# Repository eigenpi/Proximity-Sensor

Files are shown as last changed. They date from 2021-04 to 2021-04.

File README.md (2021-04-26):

cristinel.ababei, 2021 

Project: Proximity Sensor Design

--Description: 
This is a plug-and-play printed circuit board (PCB) proximity sensor design. It detects metal targets approaching perpendicularly as well as their moving direction. It uses an inductance to digital converter circuit. Machine learning models are used to differentiate between different types of metals (in V2 only). All HW and SW source files are included. HW includes PCB layout files in KiCad and SW includes firmware for the microcontroller (Atmega328p). 

--Short video domonstration: 
https://youtu.be/9pmw1QUPN_U

--More details in conference paper:
[1] Cristinel Ababei and James E. Richie, Sensor Design for Inductive Proximity and Moving Direction Sensing of Metal Targets, IEEE Int. Conf. on Modern Circuits and Systems Technologies (MOCAST), Thessaloniki, Greece, July 2021.

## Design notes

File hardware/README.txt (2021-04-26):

cristinel.ababei, 2020

These are KiCad complete projects for:

--Base board
ProximityMother_V1/

--Single LC tank, 7 turns
ProximityTankOne_Square7Turns/

--Dual LC tank, 14 turns each
ProximityTankTwo_V1/

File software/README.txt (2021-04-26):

cristinel.ababei, 2020

Code here is used in the first generation of a proximity sensor design formed by:

1--base board = Atmega328p + LDC inductance to digital converter
   this is called also Proximity Board in the comments of the code here;
2--two separate sensor boards, one LC tanks, two LC tanks
   each of the sensor boards is a plug-and-play board; the one with one LC tank
   can be used for detecting metal targets approaching perpendicularly to
   the sensor board plane' the sensor board with two LC tanks can be used for
   detecting metal targets moving laterally;

The LDC inductance to digital converter has two operation modes, which
you can select in the code below by selecting one of the following when
the "my_ldc" variable is declared:
1-- LDC_LHR_OPERATION (high-resolution, 24 it, inductance measurement) <--- default 
2-- LDC_RP_PLUS_L_OPERATION (equivalent parallel resistance RP and inductance, 16 bit, measurement)

NOTES:

1) The board uses the Atmega328p, 3.3V supply, and a crystal 8MHz.
If you power it with the USB-2-UART converter, set the jumper on 5V.

2) Please see the additional documentation and files of this project for details:
Our papers and the report for this project, the source code on github and 
PCB layout files. See the LDC1101 datasheet NOW to be in a good position to
read this code!

3) ProximityBoard is programmed in the easiest way from Arduino IDE - just like 
an Arduino Pro Mini board (3.3V) because this is how I designed it. 
But, not all the pins are with the same meaning/definition
as for an actual Pro Mini. To understand that you need to look at the schematic
diagram of the ProximityBoard and at the pin-out diagram of the ProMini.
The other way you can code and program the ProximityBoard is by using directly avrdude.

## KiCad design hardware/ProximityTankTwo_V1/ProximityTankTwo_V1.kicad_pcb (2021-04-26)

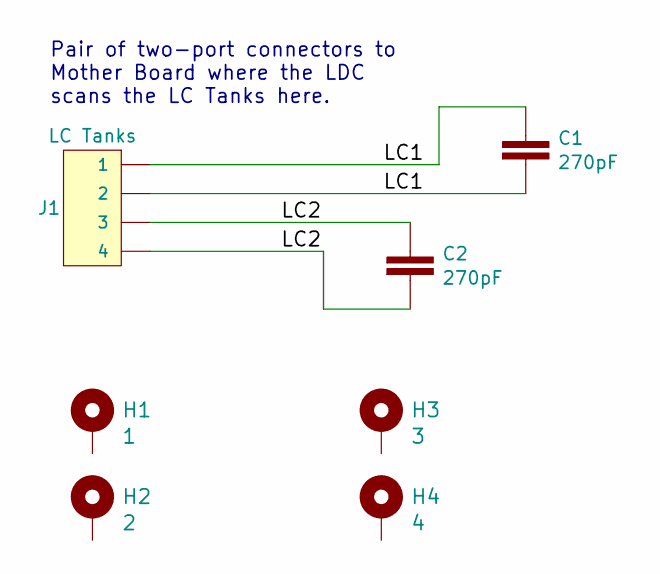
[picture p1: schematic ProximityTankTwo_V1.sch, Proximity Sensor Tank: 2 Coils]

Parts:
C1, C2: 270pF; C_0805_2012Metric_Pad1.15x1.40mm_HandSolder
H1: 1; STANDOFF_GROUNDING
H2: 2; STANDOFF_GROUNDING
H3: 3; STANDOFF_GROUNDING
H4: 4; STANDOFF_GROUNDING
J1: LC Tanks; 1X04

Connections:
/LC1: C1.1, C1.2, J1.1, J1.2
/LC2: C2.1, C2.2, J1.3, J1.4

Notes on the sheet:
Pair of two-port connectors to Mother Board where the LDC scans the LC Tanks here.

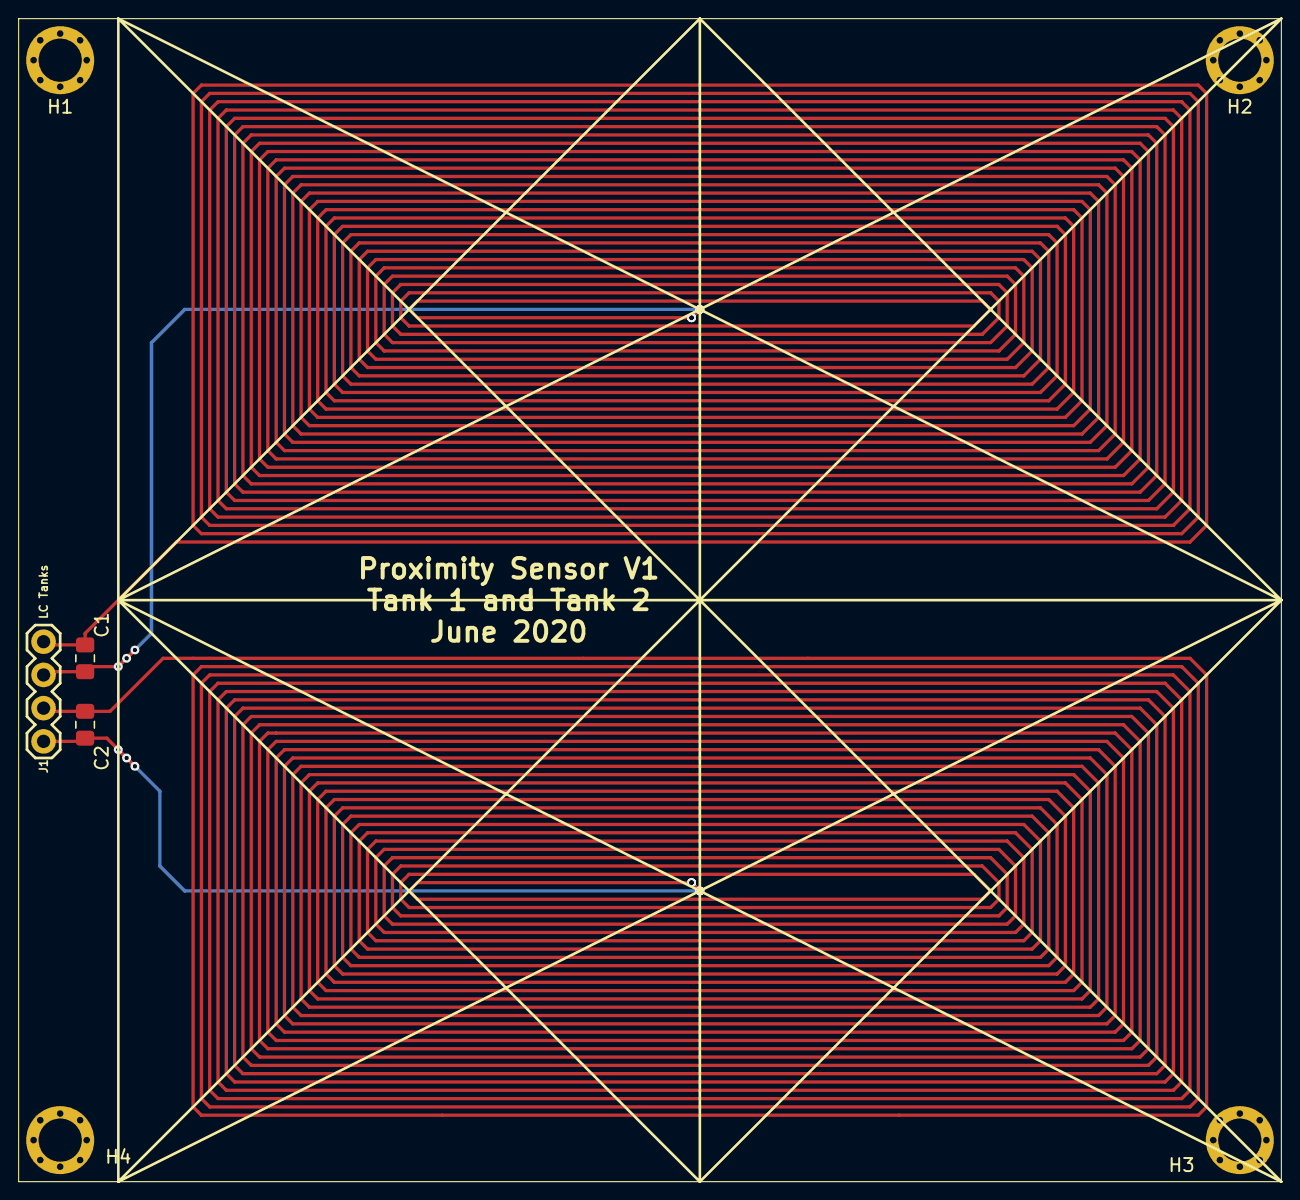
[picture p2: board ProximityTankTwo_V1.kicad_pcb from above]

Board: 2 copper layers, 7 parts (0 on the bottom side), 2 nets.

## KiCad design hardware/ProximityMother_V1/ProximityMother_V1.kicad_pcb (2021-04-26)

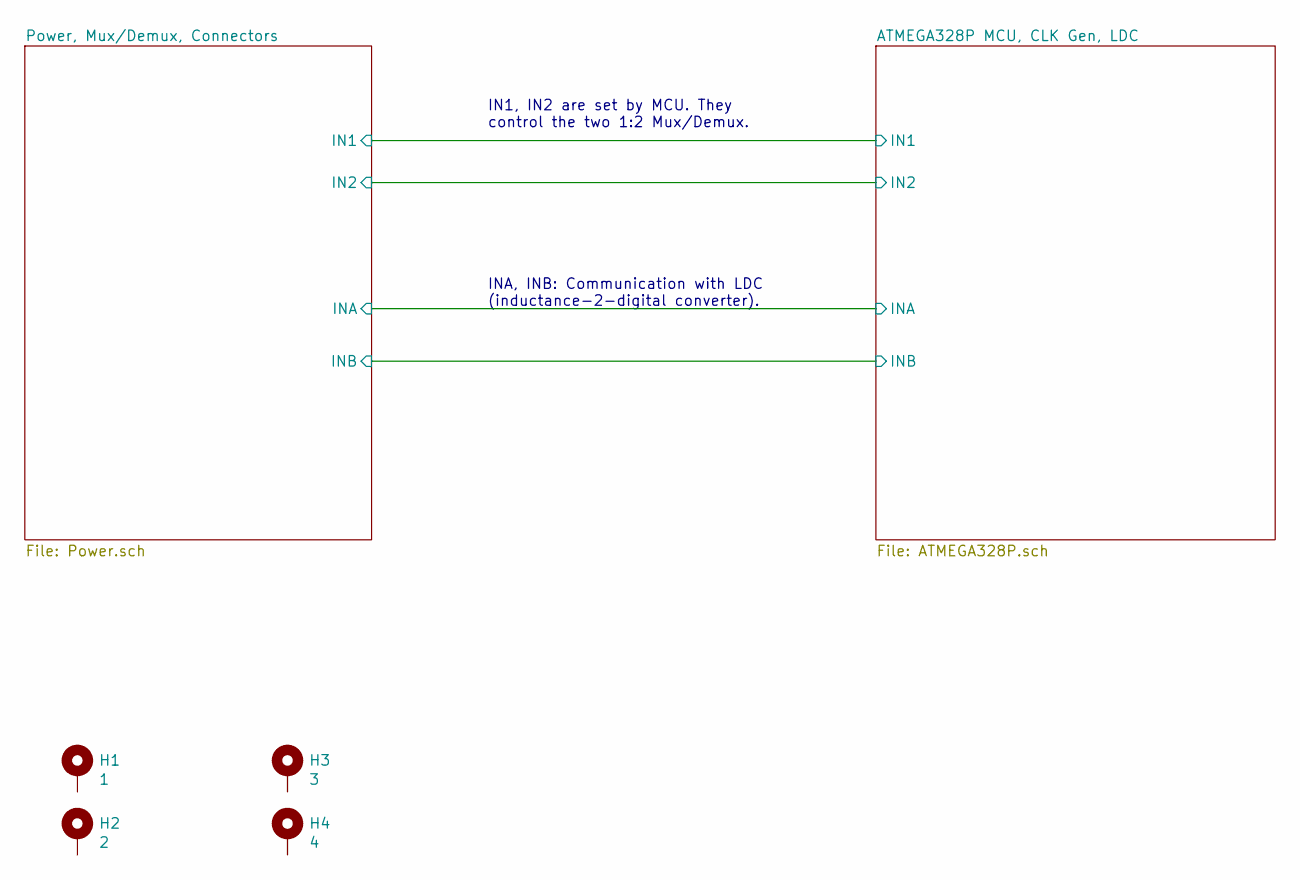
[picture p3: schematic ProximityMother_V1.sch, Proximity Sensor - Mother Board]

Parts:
H1: 1; STANDOFF_GROUNDING
H2: 2; STANDOFF_GROUNDING
H3: 3; STANDOFF_GROUNDING
H4: 4; STANDOFF_GROUNDING

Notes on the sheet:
IN1, IN2 are set by MCU. They control the two 1:2 Mux/Demux.
INA, INB: Communication with LDC (inductance-2-digital converter).

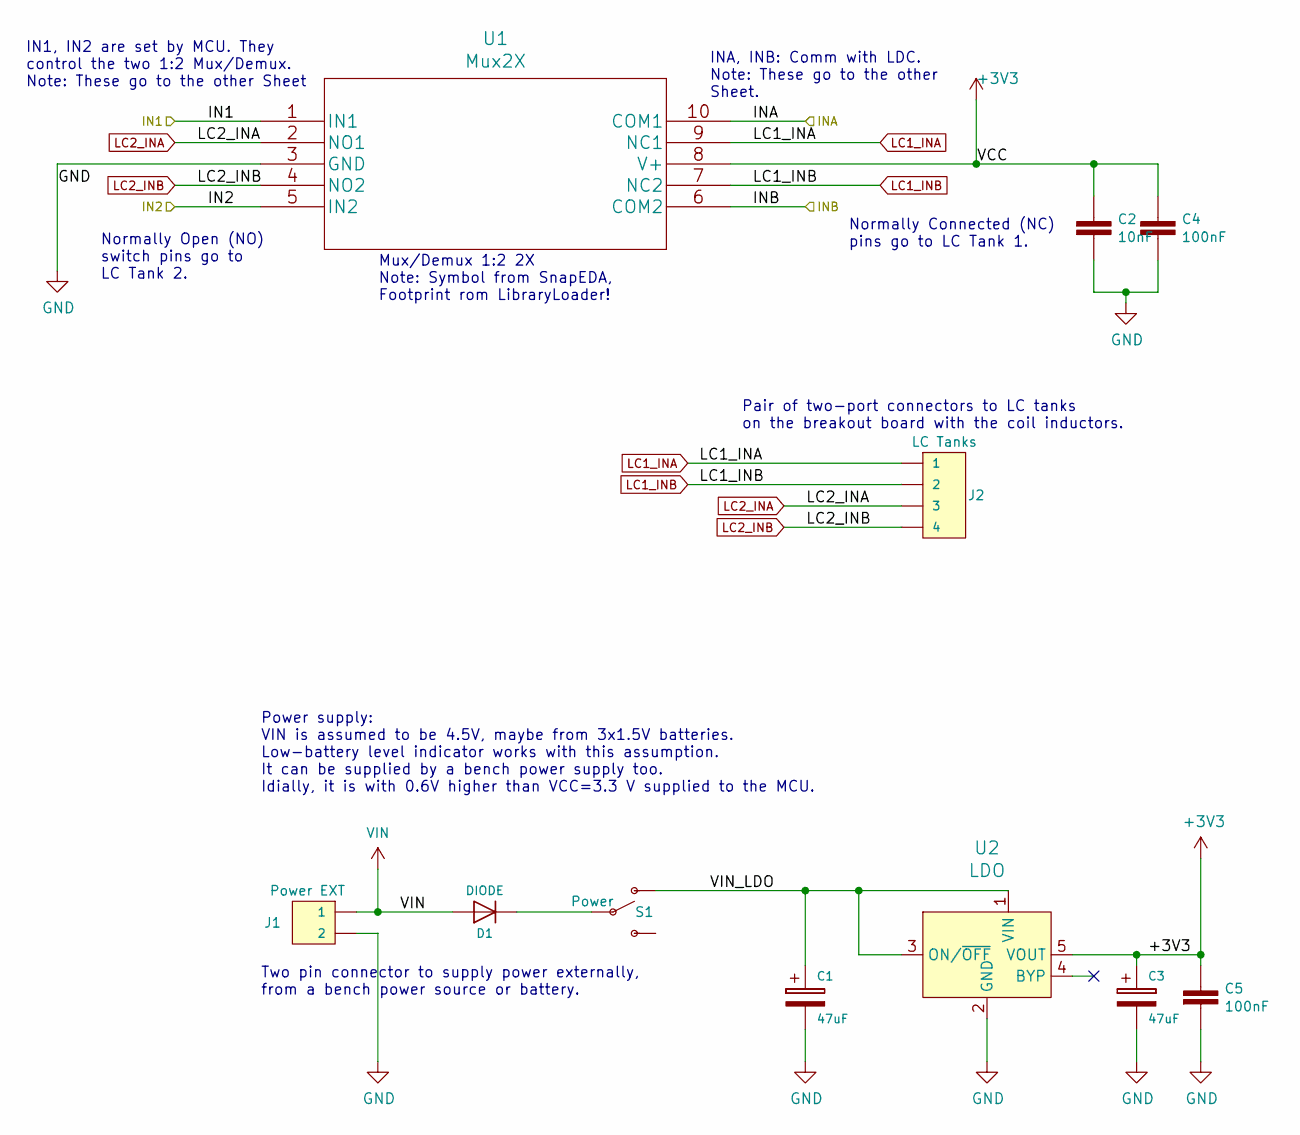
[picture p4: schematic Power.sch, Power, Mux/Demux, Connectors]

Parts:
C1, C3: 47uF; CP_Elec_5x4.5
C2: 10nF; C_1210_3225Metric_Pad1.42x2.65mm_HandSolder
C4, C5: 100nF; C_1210_3225Metric_Pad1.42x2.65mm_HandSolder
D1: DIODE; D_SOD-323_HandSoldering
J1: Power EXT; 1X02
J2: LC Tanks; 1X04
S1: Power; SWITCH_SPDT_PTH_11.6X4.0MM
U1: Mux2X; SOP50P490X110-10N
U2: LDO; SOT-753; MPN LP2985-33DBVR; Digi-Key_PN 296-18476-1-ND

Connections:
+3V3: C2.1, C3.1, C4.1, C5.1, U1.8 (V+), U2.5 (VOUT); also elsewhere on the board
/ATMEGA328P MCU, CLK Gen, LDC/INA: U1.10 (COM1); also elsewhere on the board
/ATMEGA328P MCU, CLK Gen, LDC/INB: U1.6 (COM2); also elsewhere on the board
/Power, Mux/Demux, Connectors/VIN_LDO: C1.1, S1.1 (O), U2.1 (VIN), U2.3 (ON/~OFF)
CTRL_MUX12: U1.1 (IN1), U1.5 (IN2); also elsewhere on the board
GND: C1.2, C2.2, C3.2, C4.2, C5.2, J1.2, U1.3 (GND), U2.2 (GND); also elsewhere on the board
LC1_INA: J2.1, U1.9 (NC1)
LC1_INB: J2.2, U1.7 (NC2)
LC2_INA: J2.3, U1.2 (NO1)
LC2_INB: J2.4, U1.4 (NO2)
unnamed: D1.1 (K), S1.2
VIN: D1.2 (A), J1.1; also elsewhere on the board

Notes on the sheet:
Power supply: VIN is assumed to be 4.5V, maybe from 3x1.5V batteries. Low-battery level indicator works with this assumption. It can be supplied by a bench power supply too. Idially, it is with 0.6V higher than VCC=3.3 V supplied to the MCU.
Two pin connector to supply power externally, from a bench power source or battery.
Mux/Demux 1:2 2X Note: Symbol from SnapEDA, Footprint rom LibraryLoader!
INA, INB: Comm with LDC. Note: These go to the other Sheet.
IN1, IN2 are set by MCU. They control the two 1:2 Mux/Demux. Note: These go to the other Sheet
Pair of two-port connectors to LC tanks on the breakout board with the coil inductors.
Normally Connected (NC) pins go to LC Tank 1.
Normally Open (NO) switch pins go to LC Tank 2.

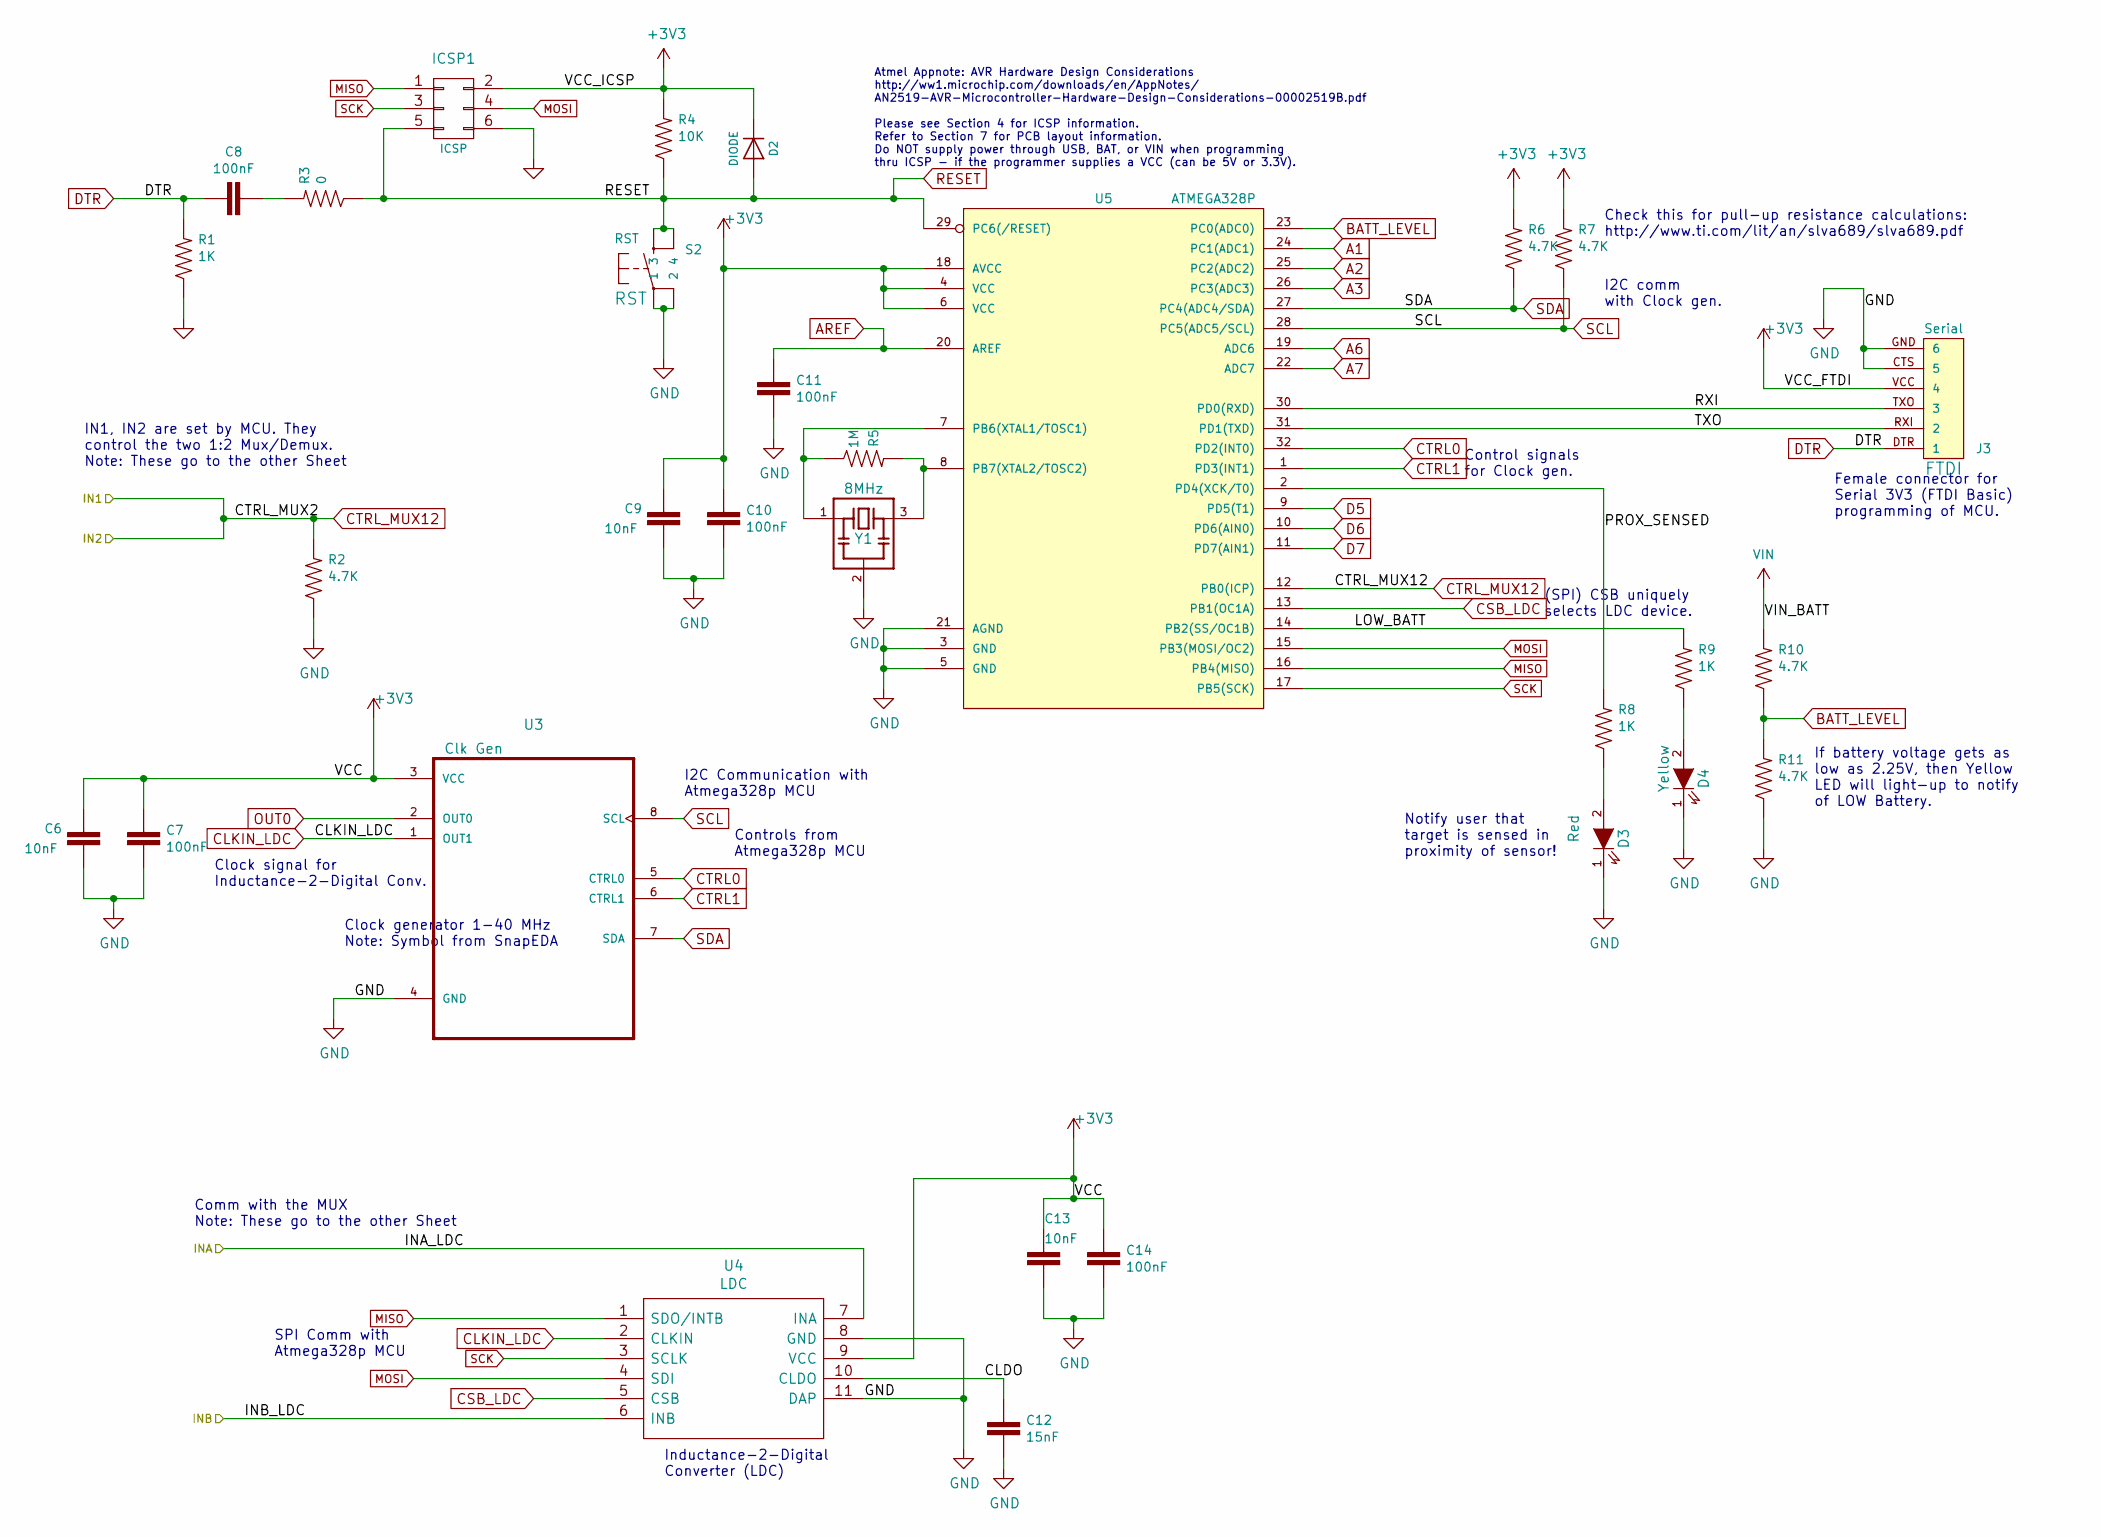
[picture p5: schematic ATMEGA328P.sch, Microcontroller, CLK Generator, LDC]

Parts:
C6, C9, C13: 10nF; C_1210_3225Metric_Pad1.42x2.65mm_HandSolder
C7, C8, C10, C11, C14: 100nF; C_1210_3225Metric_Pad1.42x2.65mm_HandSolder
C12: 15nF; C_1210_3225Metric_Pad1.42x2.65mm_HandSolder
D2: DIODE; D_SOD-323_HandSoldering
D3: Red; LED_1206_3216Metric
D4: Yellow; LED_1206_3216Metric
ICSP1: ICSP; 2X3
J3: Serial; FTDI_BASIC
R1, R8, R9: 1K; R_1210_3225Metric_Pad1.42x2.65mm_HandSolder
R2, R6, R7, R10, R11: 4.7K; R_1210_3225Metric_Pad1.42x2.65mm_HandSolder
R3: 0; R_1210_3225Metric_Pad1.42x2.65mm_HandSolder
R4: 10K; R_0805_2012Metric_Pad1.15x1.40mm_HandSolder
R5: 1M; R_1210_3225Metric_Pad1.42x2.65mm_HandSolder
S2: RST; TL3305AF160QG
U3: Clk Gen; SOIC127P600X175-8N
U4: LDC; TPS74901DRCR; Mouser Part Number 595-LDC1101DRCR
U5: ATMEGA328P; TQFP32-08
Y1: 8MHz; CSTNE8M00G55A000R0

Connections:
+3V3: C6.1, C7.1, C9.1, C10.1, C13.1, C14.1, D2.1 (K), ICSP1.2, J3.VCC (4), R4.2, R6.2, R7.2, U3.3 (VCC), U4.9 (VCC), U5.4 (VCC), U5.6 (VCC), U5.18 (AVCC); also elsewhere on the board
/ATMEGA328P MCU, CLK Gen, LDC/INA: U4.7 (INA); also elsewhere on the board
/ATMEGA328P MCU, CLK Gen, LDC/INB: U4.6 (INB); also elsewhere on the board
/ATMEGA328P MCU, CLK Gen, LDC/LOW_BATT: R9.2, U5.14 (PB2(SS/OC1B))
/ATMEGA328P MCU, CLK Gen, LDC/PROX_SENSED: R8.2, U5.2 (PD4(XCK/T0))
/ATMEGA328P MCU, CLK Gen, LDC/RXI: J3.TXO (3), U5.30 (PD0(RXD))
/ATMEGA328P MCU, CLK Gen, LDC/TXO: J3.RXI (2), U5.31 (PD1(TXD))
A1: U5.24 (PC1(ADC1))
A2: U5.25 (PC2(ADC2))
A3: U5.26 (PC3(ADC3))
A6: U5.19 (ADC6)
A7: U5.22 (ADC7)
AREF: C11.2, U5.20 (AREF)
BATT_LEVEL: R10.1, R11.2, U5.23 (PC0(ADC0))
CLKIN_LDC: U3.1 (OUT1), U4.2 (CLKIN)
CSB_LDC: U4.5 (CSB), U5.13 (PB1(OC1A))
CTRL0: U3.5 (CTRL0), U5.32 (PD2(INT0))
CTRL1: U3.6 (CTRL1), U5.1 (PD3(INT1))
CTRL_MUX12: R2.2, U5.12 (PB0(ICP)); also elsewhere on the board
D5: U5.9 (PD5(T1))
D6: U5.10 (PD6(AIN0))
D7: U5.11 (PD7(AIN1))
DTR: C8.1, J3.DTR (1), R1.2
GND: C6.2, C7.2, C9.2, C10.2, C11.1, C12.1, C13.2, C14.2, D3.1 (K), D4.1 (K), ICSP1.6, J3.CTS (5), J3.GND (6), R1.1, R2.1, R11.1, S2.1, S2.2, U3.4 (GND), U4.8 (GND), U4.11 (DAP), U5.3 (GND), U5.5 (GND), U5.21 (AGND), Y1.2; also elsewhere on the board
MISO: ICSP1.1, U4.1 (SDO/INTB), U5.16 (PB4(MISO))
MOSI: ICSP1.4, U4.4 (SDI), U5.15 (PB3(MOSI/OC2))
unnamed: C8.2, R3.2
unnamed: C12.2, U4.10 (CLDO)
unnamed: D3.2 (A), R8.1
unnamed: D4.2 (A), R9.1
unnamed: R5.1, U5.7 (PB6(XTAL1/TOSC1)), Y1.1
unnamed: R5.2, U5.8 (PB7(XTAL2/TOSC2)), Y1.3
OUT0: U3.2 (OUT0)
RESET: D2.2 (A), ICSP1.5, R3.1, R4.1, S2.3, S2.4, U5.29 (PC6(/RESET))
SCK: ICSP1.3, U4.3 (SCLK), U5.17 (PB5(SCK))
SCL: R7.1, U3.8 (SCL), U5.28 (PC5(ADC5/SCL))
SDA: R6.1, U3.7 (SDA), U5.27 (PC4(ADC4/SDA))
VIN: R10.2; also elsewhere on the board

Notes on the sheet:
Atmel Appnote: AVR Hardware Design Considerations http://ww1.microchip.com/downloads/en/AppNotes/ AN2519-AVR-Microcontroller-Hardware-Design-Considerations-00002519B.pdf Please see Section 4 for ICSP information. Refer to Section 7 for PCB layout information. Do NOT supply power through USB, BAT, o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
Control signals for Clock gen.
Check this for pull-up resistance calculations: http://www.ti.com/lit/an/slva689/slva689.pdf
If battery voltage gets as low as 2.25V, then Yellow LED will light-up to notify of LOW Battery.
Female connector for Serial 3V3 (FTDI Basic) programming of MCU.
Inductance-2-Digital Converter (LDC)
Clock generator 1-40 MHz Note: Symbol from SnapEDA
I2C Communication with Atmega328p MCU
Clock signal for Inductance-2-Digital Conv.
I2C comm with Clock gen.
Controls from Atmega328p MCU
Comm with the MUX Note: These go to the other Sheet
IN1, IN2 are set by MCU. They control the two 1:2 Mux/Demux. Note: These go to the other Sheet
(SPI) CSB uniquely selects LDC device.
Notify user that target is sensed in proximity of sensor!
SPI Comm with Atmega328p MCU

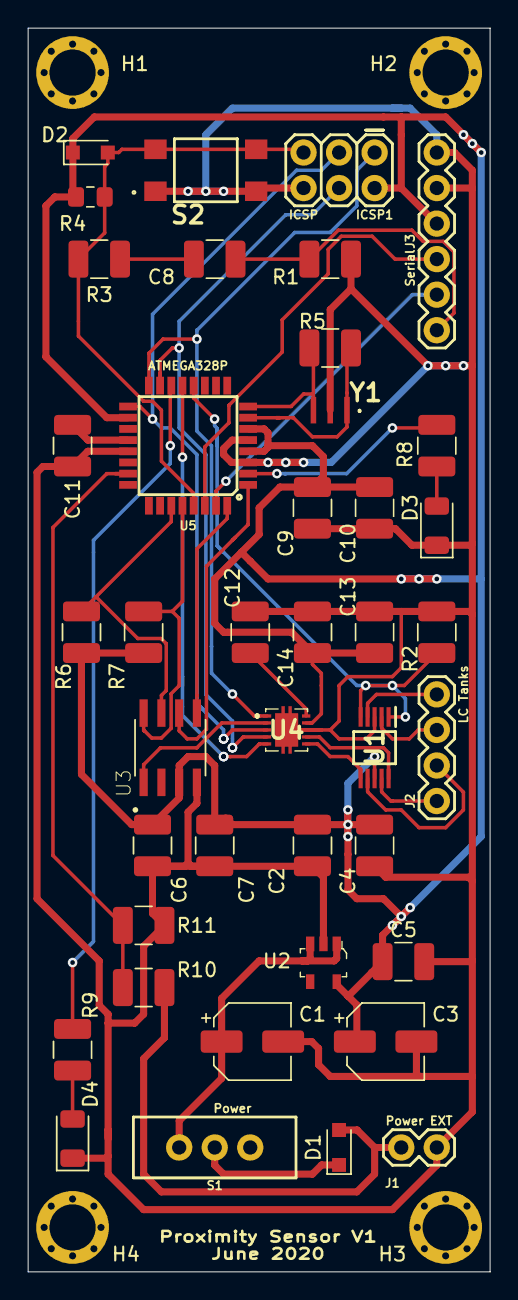
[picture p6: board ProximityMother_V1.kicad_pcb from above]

Board: 2 copper layers, 33.0 x 88.9 mm, 45 parts (0 on the bottom side), 35 nets.

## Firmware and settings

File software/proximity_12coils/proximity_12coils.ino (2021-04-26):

// cristinel.ababei, jim.richie, copyleft :-), october 2020
//
// this is a collaboration project between cristinel ababei and jim richie
// at marquette, electrical and computer engr. department
// 
// code here is used in the first generation of a proximity sensor design formed by:
// 1--base board = Atmega328p + LDC inductance to digital converter
//    this is called also Proximity Board in the comments of the code here;
// 2--two separate sensor boards, one LC tanks, two LC tanks
//    each of the sensor boards is a plug-and-play board; the one with one LC tank
//    can be used for detecting metal targets approaching perpendicularly to
//    the sensor board plane' the sensor board with two LC tanks can be used for
//    detecting metal targets moving laterally;
// 
// the LDC inductance to digital converter has two operation modes, which
// you can select in the code below by selecting one of the following when
// the "my_ldc" variable is declared:
// 1-- LDC_LHR_OPERATION (high-resolution, 24 it, inductance measurement) <--- default 
// 2-- LDC_RP_PLUS_L_OPERATION (equivalent parallel resistance RP and inductance, 16 bit, measurement)
//
// Notes:
// 
// Please see the additional documentation and files of this project for details:
// Our papers and the report for this project, the source code on github and 
// PCB layout files. See the LDC1101 datasheet NOW to be in a good position to
// read this code!
//
// ProximityBoard is programmed in the easiest way from Arduino IDE - just like 
// an Arduino Pro Mini board (3.3V) because this is how I designed it. 
// But, not all the pins are with the same meaning/definition
// as for an actual Pro Mini. To understand that you need to look at the schematic
// diagram of the ProximityBoard and at the pin-out diagram of the ProMini.
// The other way you can code and program the ProximityBoard is by using directly avrdude.
//
// In the ProximityBoard design I made the mistake to use the SS pin of 
// the SPI peripheral as battery low pin to drive an LED; and, instead
// I used PB1 as a pin with the function of slave select to use to 
// connect to the LDC; I should have used these two pins swapped! will do next time;
// for now, I need to replacce the IDE pin SS with PB1 (IDE pin 9) so that the LDC
// will be selected correctly as a Slave chip, by the MCU Atmega328p the master;
//
// That is why I duplicated the SPIClass which is the type-of that the SPI object
// defined by Arduino IDE; so, inside that class the standard SS (IDE pin 10) should
// be substituted with IDE pin 9, which I have used in the ProximityBoard;
// I created a new class SPIClass2 inside SPI2.h and SPI2.cpp to get around that;
// So much pain for the swapping two pins... mistakes cost. :-)
//
// the other Arduino Pro Mini's pins that are used as SPI pins are the standard ones
// (see Arduini Pro Mini pinout diagram): 
// MOSI    IDE pin 11: is MCU pin 15
// MISO    IDE pin 12: is MCU pin 16
// SCK     IDE pin 13: is MCU pin 17

#include <Wire.h> 
#include "ldc1101.h"


#define DEBUG false


// Thresholds used to mark that metal target approached the sensor;
#define THRESHOLD_PERCENTAGE_CHANGE_LHR_DATA 3.0
#define THRESHOLD_PERCENTAGE_CHANGE_fSENSOR  3.0


// DS1077L - Dallas Semiconductor Maxim clock generator
//
// I use it to generate a clock of 10 MHz for the LDC1101;
// It needs to be configured via I2C by the MCU Atmega328;
// DS1077L can generate an oscillator frequency in the range 4.87kHz to 66.666MHz
// https://www.sparkfun.com/products/retired/9116

#define DS1077L_ADDRESS 0x58 // DS1077L default address 0x58


// LDC1101 - TI's inductance to digital converter
//
// MCU Atmega328p is connected to the inductance to digital converter LDC1101;
// they talk via SPI;
// create LDC1101 object to talk to the inductance-to-digital converter chip via SPI2;
// ss_pin is IDE pin 9; 
// capacitor = 270pF
// f_CLKIN = 10MHz: frequency of external clock generated by clock-gen
// _operation_mode is: LDC_LHR_OPERATION (default!) or LDC_RP_PLUS_L_OPERATION

LDC1101 my_ldc(9, 270E-12, 10000000.0, LDC_LHR_OPERATION); 


char str_temp[64];
char temp[64];
// visual of how boards are attached:
// ----------     ----------
//           | --|
//           | --| LC2 tank(default)
// Base Board| --|                  Sensor Board
//           | --| LC1 tank 
// ----------     ----------
// by default single LC2 tank sensor board are connected what on the schematic diagram
// of the base board is LC2 port (upper port); so, by default we would work with just
// one LC tank connected to port #2; that is why I use these variables ID-ed with 2:
uint32_t prev_LHR_data2 = 0;
uint32_t curr_LHR_data2 = 0;
double change_in_LHR_data2 = 0.0; 
double prev_fsensor2 = 0.0;
double curr_fsensor2 = 0.0;
double percent_change_in_fSENSOR2 = 0.0;
double delta_fSENSOR2 = 0.0;
// variables for working with LC1 tank, when it exists
uint32_t prev_LHR_data1 = 0;
uint32_t curr_LHR_data1 = 0;
double change_in_LHR_data1 = 0.0; 
double prev_fsensor1 = 0.0;
double curr_fsensor1 = 0.0;
double percent_change_in_fSENSOR1 = 0.0;
double delta_fSENSOR1 = 0.0;
// keep track of whether target was detected from RIGHT or from LEFT
boolean target_detected_right = false; // by LC2 tank
boolean target_detected_left = false;  // by LC1 tank

// sketch variables;
uint32_t curr_LHR_data_to_ignore = 0;
boolean have_driven_LC2 = false; 
int my_counter = 0;

// in this implementation the proximity sensor can have:
// either one LC2 tank with L covering the whole plane of the sensor; 
// or, two tanks, LC1 & LC2 which are used to detect direction of metal target;
boolean exists_LC1 = false;
boolean exists_LC2 = false;


///////////////////////////////////////////////////////////////////////////////
//
// setup
//
///////////////////////////////////////////////////////////////////////////////

void setup() 
{
  // () after the ProximityBoard (programmed as an Arduino Pro Mini) is programmed, 
  // we use Arduino's serial terminal as a debugging interface, to print stuff, etc.;
  Serial.begin(9600);
  Serial.print("********************************************************* \r\n"); 
  Serial.print("Started Serial... \r\n");
  
  
  // () start the I2C library; used to talk to the DS1077L clock generator;
  Serial.print("********************************************************* \r\n");
  Serial.print("Configure clock-generator: DS1077L: \r\n");
  Wire.begin();
  //read_print_DS1077L_registers();
  init_DS1077L_clock_generator(); 
  read_print_DS1077L_registers(); 

  
  // () check vitals of the sensor LDC1101 inductance to digital converter;
  Serial.print("********************************************************* \r\n");
  Serial.print("Check status of inductance to digital converter: LDC1101... \r\n");
  query_LDC1101_device_during_setup( DEBUG);

  // the MCU pin 2 (or PD4), which is IDE pin 4 drives the RED LED to
  // signal that metal target entered the sensor's vicinity;
  // so, set this pin as out here; 
  pinMode(4, OUTPUT);
  digitalWrite(4, LOW);
  
  
  // () configure the MUX to connect tank LC2 to the inductance-to-digital converter;
  // the MUX is the "TS5A23157 Dual 10-Ω SPDT Analog Switch" IC, which
  // I control with PB0 (IDE pin 8, also MCU pin 12); 
  // to control the MUX to select LC2 (i.e., LC2_INA and LC2_INB) I need to set the control pin HIGH;
  Serial.print("********************************************************* \r\n");
  Serial.print("Configure MUX: TS5A23157 Dual 10-Ω SPDT Analog Switch... \r\n");
  pinMode(8, OUTPUT);
  
  // identify if we have a board sensor with just one LC tank (LC2)
  // or two LC tanks (for direction detection);
  scan_LC_tank_ports(); // will drive IDE pin 8 high and low
  get_one_time_current_frequency(); // read from LDC and set "curr" frequency(ies)
  digitalWrite(8, HIGH); // place the MUX on default connecting to LC2 tank that always should exist 
  
  
  // () Low Battery LED (should have been SS pin for the SPI bus!);
  // we blink it for debug purposes;
  pinMode(10, OUTPUT);
  digitalWrite(10, HIGH);
  
  
  // () done setup;
  Serial.print("\r\nDone setup \r\n");
  Serial.print("********************************************************* \r\n");
}


///////////////////////////////////////////////////////////////////////////////
//
// main loop
//
///////////////////////////////////////////////////////////////////////////////

void loop() 
{
  
  // print debug info;
  //my_counter++; Serial.print(my_counter); Serial.print("\r\n");
  print_debug_information_during_loop( DEBUG);
  


  // () PART 1: LDC_LHR_OPERATION (default!)
  // get raw measured data for inductance;
  // then, compute fSENSOR and LSENSOR;
  // look at the sign or direction of change of fSENSOR; when freq increases
  // turn the red LED on; that is target is approaching; let user know;
  // if direction sensing turn red LED on and signal in serial terminal; 
  if ( my_ldc.get_operation_mode() == LDC_LHR_OPERATION ) { // default    
    // ------------------------- CASE #1 -------------------------
    if ( exists_LC2 == true && exists_LC1 == false) { 
      check_metal_target_approaching_perpendicularly();
    } 
    // ------------------------- CASE #2 -------------------------
    if ( exists_LC2 == true && exists_LC1 == true) { 
      check_metal_target_moving_from_RIGHT();
      check_metal_target_moving_from_LEFT();
      // reset;
      if ( target_detected_right == true || target_detected_left == true) { 
        target_detected_right = false;
        target_detected_left = false;
        get_one_time_current_frequency();   
      }
    } 
  } 
  
  // PART 2:
  // Note 1: to get into this branch of this "if" statement, you must use the
  // approapriate argument when the "my_ldc" variable is declared at the top of this file!
  // Note 2: here I only read and print in the terminal the values provided by the LDC converter;
  // I am NOT using those for anything; feel free to build your own logic here as
  // I did in Part 1 above, which is my default mode of operation;
  else { // LDC_RP_PLUS_L_OPERATION
    print_debug_information_during_loop( true);
  } 

}


///////////////////////////////////////////////////////////////////////////////
//
// I2C functions
// DS1077L - clock generator (frequency synthesizer)
//
///////////////////////////////////////////////////////////////////////////////

void i2c_write(int device, byte address) 
{
  Wire.beginTransmission(device); //start transmission to device 
  Wire.write(address);        // send register address
  Wire.endTransmission(); //end transmission
}

void i2c_write(int device, byte address, byte val1) 
{
  Wire.beginTransmission(device); //start transmission to device 
  Wire.write(address);        // send register address
  Wire.write(val1);        // send value to write
  Wire.endTransmission(); //end transmission
}

void i2c_write(int device, byte address, byte val1, byte val2) 
{
  Wire.beginTransmission(device); //start transmission to device 
  Wire.write(address);        // send register address
  Wire.write(val1);        // send value to write
  Wire.write(val2);        // send value to write
  Wire.endTransmission(); //end transmission
}

void init_DS1077L_clock_generator() 
{
  // initialize DS1077L
  // The master oscillator used in the DS1077L is a CMOS oscillator with compensation circuitry;
  // Four standard master frequency options are available: 40MHz, 50MHz, 60MHz, and 66.66MHz;
  // I goot from Digikey the one with reference frequency 40MHz (should have gotten the 60MHz);
  // We want the 40MHz, which we devide by 4 to get a 10MHz to the OUT1 of the clock-gen, which we feed
  // into LDC1101;
  
  // (1) set CTRL0 and CTRL1 of the clock generator to 0; reccommended;
  // these are connected to PD2 and PD3 of the Atmega328p MCU in teh ProximityBoard;
  // that is Arduino IDE pins 2 and 3;
  pinMode(2, OUTPUT);
  digitalWrite(2, LOW);
  pinMode(3, OUTPUT);
  digitalWrite(3, LOW);

  // (2) See Datasheet for the info below!
  // MUX WORD:   first data byte                      second data byte
  // Name:       * PDN1 PDN0 SEL0 EN0 0M1 0M0 1M1     1M0 DIV1 - - - - - -
  // Default:    0 0    0    1    1   0   0   0       0   0    x x x x x x
  // My settings:0 0    0    0    0   0   0   0       0   0    0 0 0 0 0 0 <--- 0x00, 0x00
  //
  // DIV WORD:
  // MSB                  LSB   MSB             LSB
  // N9 N8 N7 N6 N5 N4 N3 N2    N1 N0 X X X X X X
  // first data byte            second data byte
  // N9:0: These ten bits determine the value of the programmable divider (N). 
  // The range of divisor values is from 2 to 1025, and is equal to the programmed value of N plus 2.
  // So, knowing that the master frequency is 40MHz, to get out a 10MHz, I would need to:
  // -- keep above 1M to 00 (so that the PRESCALER P1 DIVISOR “M” is 1 - see Table 4 in Datasheet)
  // -- set N here with my settings:
  // 0  0  0  0  0  0  0  0     1  0  0 0 0 0 0 0 <--- 0x00, 0x80
  // which means a divisor value of 2 + 2 = 4 because that would give me 40MHz/4 = 10MHz
  
  i2c_write(DS1077L_ADDRESS, 0x02, 0x00, 0x00); // write MUX
  i2c_write(DS1077L_ADDRESS, 0x01, 0x00, 0x80); // write DIV
  i2c_write(DS1077L_ADDRESS, 0x0D, 0x08); // WC = 1, the EEPROM is only written when the WRITE command is issued (Datasheet page 7)
  i2c_write(DS1077L_ADDRESS, 0x3F); // write E2
  delay(500); 
}

void read_print_DS1077L_registers() 
{
  uint16_t sketch_reg=0;
  
  Wire.beginTransmission(DS1077L_ADDRESS); // Start communication with DS1077L
  Wire.write(0x02);                        // Start reading at register 02 == MUX
  Wire.endTransmission();                  // End the transmission
  Wire.requestFrom(DS1077L_ADDRESS, 2);    // Request 2 bytes from the DS1077L
  sketch_reg = Wire.read()<<8|Wire.read(); 
  Serial.print("MUX: "); Serial.print(sketch_reg, HEX); Serial.print(" \r\n");
  
  sketch_reg=0;
  Wire.beginTransmission(DS1077L_ADDRESS); 
  Wire.write(0x01);                        // Start reading at register 01 == DIV
  Wire.endTransmission();                  
  Wire.requestFrom(DS1077L_ADDRESS, 2);    
  sketch_reg = Wire.read()<<8|Wire.read(); 
  Serial.print("DIV: "); Serial.print(sketch_reg, HEX); Serial.print(" \r\n");   
}


///////////////////////////////////////////////////////////////////////////////
//
// Functions for working with the LDC sensor
// RP+L or LHR mode
//
///////////////////////////////////////////////////////////////////////////////

void query_LDC1101_device_during_setup( boolean debug)
{
  // debugging purposes only; used during setup;
  
  uint32_t LHR_data = 0;
  uint16_t L_data = 0;
  uint16_t RESP_TIME = 0;
  uint16_t RCOUNT = 13;

  if ( my_ldc.get_operation_mode() == LDC_LHR_OPERATION ) { // default
    Serial.print("Inductance-to-digital converter mode of operation: LHR\r\n");
  } else { // LDC_RP_PLUS_L_OPERATION
    Serial.print("Inductance-to-digital converter mode of operation: RP+L\r\n");
  }
  
  if ( debug == true) {   
    // RCOUNT
    RCOUNT = my_ldc.get_Rcount(); // <--- does a readSPI
    Serial.print("RCOUNT = "); Serial.print(RCOUNT); Serial.print("\r\n");

    // RESP_TIME: 384 (default value) corresponts to "#" stored in DIG_CONF register
    RESP_TIME = my_ldc.get_responsetime(); // <--- does a readSPI
    Serial.print("RESP_TIME = "); Serial.print(RESP_TIME); Serial.print("\r\n");
    
    // f_CLKIN: frequency of external clock: 10MHz in my case
    dtostrf(my_ldc.get_fCLKIN(), 16, 2, str_temp); 
    sprintf(temp, "fCLKIN = %s Hz", str_temp); 
    Serial.print(temp); Serial.print("\r\n");

    // Parallel capacitance 
    dtostrf(my_ldc.get_cap(), 24, 16, str_temp); 
    sprintf(temp, "capacitance = %s F", str_temp); 
    Serial.print(temp); Serial.print("\r\n");
     
    //LHR_data = my_ldc.get_LHR_Data(); // LHR mode <--- does a readSPI
    //Serial.print("LHR_data = "); Serial.print(LHR_data); Serial.print("\r\n");
    //L_data = my_ldc.get_L_Data(); // RP+L mode <--- does a readSPI
    //Serial.print("L_data = "); Serial.print(L_data); Serial.print("\r\n");

    // f_sensor: the calculated frequency of the sensor 
    //dtostrf(my_ldc.get_fsensor( LHR_data ), 24, 16, str_temp); 
    //dtostrf(my_ldc.get_fsensor( L_data ), 24, 16, str_temp);
    //sprintf(temp, "fsensor, frequency = %s Hz", str_temp); 
    //Serial.print(temp); Serial.print("\r\n");
    
    // _inductance = 1./(_cap * 4*PI*PI*fsensor*fsensor); 
    //dtostrf(my_ldc.get_Inductance( LHR_data ), 24, 16, str_temp); 
    //dtostrf(my_ldc.get_Inductance( L_data ), 24, 16, str_temp); 
    //sprintf(temp, "L_SENSOR, inductance = %s H", str_temp); 
    //Serial.print(temp); Serial.print("\r\n");
  }  
} 

void print_debug_information_during_loop( boolean debug)
{
  // debugging purposes only; used during loop;

  uint8_t LHR_status = 0;
  uint32_t LHR_data = 0;
  uint8_t RPL_status = 0;
  uint16_t RP_data = 0;
  uint16_t L_data = 0;

  // poll the sensor data; the sensor, LDC1101 must be in LDC_MODE_ACTIVE_CONV
  if ( debug == true) {
    //Serial.print("\r\nMeasurement mode... \r\n");

    if ( my_ldc.get_operation_mode() == LDC_LHR_OPERATION ) { // default
    
      if ( my_ldc.is_New_LHR_data() == true) { 
          // If: '0' : Unread LHR conversion data is available.
          // If: '1' : No unread LHR conversion data is available.
          LHR_status = my_ldc.get_LHR_status(); // <--- does a readSPI
          Serial.print("LHR_status = "); Serial.print(LHR_status); Serial.print("\r\n");
          
          // raw measured data for inductance
          LHR_data = my_ldc.get_LHR_Data(); // LHR mode <--- does a readSPI
          Serial.print("LHR_data = "); Serial.print(LHR_data); Serial.print("\r\n");
          
          // f_sensor: the calculated frequency of the sensor 
          // _fsensor = two_to_divider * _fCLKIN * (Ldata + _LHRoffset*256)/16777216; // Hz
          dtostrf(my_ldc.get_fsensor( LHR_data ), 24, 16, str_temp); 
          sprintf(temp, "Frequency fSENSOR  = %s Hz", str_temp); 
          Serial.print(temp); Serial.print("\r\n");
          
          // _inductance = 1./(_cap * 4*PI*PI*fsensor*fsensor); 
          dtostrf(my_ldc.get_Inductance( LHR_data ), 24, 16, str_temp); 
          sprintf(temp, "Inductance L_SENSOR = %s H", str_temp); 
          Serial.print(temp); Serial.print("\r\n");
      } else {
        Serial.print("No unread LHR conversion data is available.\r\n");
      }
      
    } else { // LDC_RP_PLUS_L_OPERATION
    
      if ( my_ldc.is_RP_L_DataReady() == true) { 
        RPL_status = my_ldc.get_status(); // <--- does a readSPI
        Serial.print("status = "); Serial.print(RPL_status); Serial.print("\r\n");

        // raw measured data for inductance
        L_data = my_ldc.get_L_Data(); // RP+L mode <--- does a readSPI
        Serial.print("L_data = "); Serial.print(L_data); Serial.print("\r\n");
        
        // f_sensor: the calculated frequency of the sensor 
        // _fsensor = (_fCLKIN * 6144) / (3 * Ldata);
        dtostrf(my_ldc.get_fsensor( L_data ), 24, 16, str_temp);
        sprintf(temp, "Frequency fSENSOR  = %s Hz", str_temp);  
        Serial.print(temp); Serial.print("\r\n");
        
        // _inductance = 1./(_cap * 4*PI*PI*fsensor*fsensor); 
        dtostrf(my_ldc.get_Inductance( L_data ), 24, 16, str_temp); 
        sprintf(temp, "Inductance L_SENSOR = %s H", str_temp); 
        Serial.print(temp); Serial.print("\r\n");
         
        RP_data = my_ldc.get_RP_Data();
        Serial.print("RP_data = "); Serial.print(RP_data); Serial.print("\r\n");
        
        dtostrf(my_ldc.get_RP( RP_data ), 24, 16, str_temp);
        sprintf(temp, "RP = %s Ohm", str_temp); 
        Serial.print(temp); Serial.print("\r\n");
      } else {
        Serial.print("No new RP+L conversion data is available.\r\n");
      }  
      
    }
  }
}
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

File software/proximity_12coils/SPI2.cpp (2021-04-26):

/*
 * Copyright (c) 2010 by Cristian Maglie <c.maglie@arduino.cc>
 * Copyright (c) 2014 by Paul Stoffregen <paul@pjrc.com> (Transaction API)
 * Copyright (c) 2014 by Matthijs Kooijman <matthijs@stdin.nl> (SPISettings AVR)
 * Copyright (c) 2014 by Andrew J. Kroll <xxxajk@gmail.com> (atomicity fixes)
 * SPI Master library for arduino.
 *
 * This file is free software; you can redistribute it and/or modify
 * it under the terms of either the GNU General Public License version 2
 * or the GNU Lesser General Public License version 2.1, both as
 * published by the Free Software Foundation.
 */

#include "SPI2.h"

//SPIClass2 SPI2;
// In the ProximityBoard I use IDE pin 9 (MCU pin 13 or PB1) as Slave Select Pin;
// I should have use the default IDE pin 10 instead; That is why I need this here:
#define SS_PIN 9

uint8_t SPIClass2::initialized = 0;
uint8_t SPIClass2::interruptMode = 0;
uint8_t SPIClass2::interruptMask = 0;
uint8_t SPIClass2::interruptSave = 0;
#ifdef SPI_TRANSACTION_MISMATCH_LED
uint8_t SPIClass2::inTransactionFlag = 0;
#endif

void SPIClass2::begin()
{
  uint8_t sreg = SREG;
  noInterrupts(); // Protect from a scheduler and prevent transactionBegin
  if (!initialized) {
    
    // cris: pin 10 has to be an output because that's how you tell the hardware 
    // that it's the bus master and not a slave; I use it as output anyway to
    // drive low-battery led later on;
    pinMode(10, OUTPUT); 
    
    // Set SS_PIN to high so a connected chip will be "deselected" by default
    uint8_t port = digitalPinToPort(SS_PIN);
    uint8_t bit = digitalPinToBitMask(SS_PIN);
    volatile uint8_t *reg = portModeRegister(port);

    // if the SS_PIN pin is not already configured as an output
    // then set it high (to enable the internal pull-up resistor)
    if(!(*reg & bit)){
      digitalWrite(SS_PIN, HIGH);
    }
 
    // When the SS_PIN pin is set as OUTPUT, it can be used as
    // a general purpose output port (it doesn't influence
    // SPI operations).
    pinMode(SS_PIN, OUTPUT);

    // Warning: if the default SS pin (IDE pin 10) ever becomes a LOW INPUT then SPI
    // automatically switches to Slave, so the data direction of
    // the SS pin MUST be kept as OUTPUT.
    SPCR |= _BV(MSTR);
    SPCR |= _BV(SPE);

    // Set direction register for SCK and MOSI pin.
    // MISO pin automatically overrides to INPUT.
    // By doing this AFTER enabling SPI, we avoid accidentally
    // clocking in a single bit since the lines go directly
    // from "input" to SPI control.
    // http://code.google.com/p/arduino/issues/detail?id=888
    pinMode(SCK, OUTPUT);
    pinMode(MOSI, OUTPUT);
  }
  initialized++; // reference count
  SREG = sreg;
}

void SPIClass2::end() {
  uint8_t sreg = SREG;
  noInterrupts(); // Protect from a scheduler and prevent transactionBegin
  // Decrease the reference counter
  if (initialized)
    initialized--;
  // If there are no more references disable SPI
  if (!initialized) {
    SPCR &= ~_BV(SPE);
    interruptMode = 0;
    #ifdef SPI_TRANSACTION_MISMATCH_LED
    inTransactionFlag = 0;
    #endif
  }
  SREG = sreg;
}

// mapping of interrupt numbers to bits within SPI_AVR_EIMSK
#if defined(__AVR_ATmega32U4__)
  #define SPI_INT0_MASK  (1<<INT0)
  #define SPI_INT1_MASK  (1<<INT1)
  #define SPI_INT2_MASK  (1<<INT2)
  #define SPI_INT3_MASK  (1<<INT3)
  #define SPI_INT4_MASK  (1<<INT6)
#elif defined(__AVR_AT90USB646__) || defined(__AVR_AT90USB1286__)
  #define SPI_INT0_MASK  (1<<INT0)
  #define SPI_INT1_MASK  (1<<INT1)
  #define SPI_INT2_MASK  (1<<INT2)
  #define SPI_INT3_MASK  (1<<INT3)
  #define SPI_INT4_MASK  (1<<INT4)
  #define SPI_INT5_MASK  (1<<INT5)
  #define SPI_INT6_MASK  (1<<INT6)
  #define SPI_INT7_MASK  (1<<INT7)
#elif defined(EICRA) && defined(EICRB) && defined(EIMSK)
  #define SPI_INT0_MASK  (1<<INT4)
  #define SPI_INT1_MASK  (1<<INT5)
  #define SPI_INT2_MASK  (1<<INT0)
  #define SPI_INT3_MASK  (1<<INT1)
  #define SPI_INT4_MASK  (1<<INT2)
  #define SPI_INT5_MASK  (1<<INT3)
  #define SPI_INT6_MASK  (1<<INT6)
  #define SPI_INT7_MASK  (1<<INT7)
#else
  #ifdef INT0
  #define SPI_INT0_MASK  (1<<INT0)
  #endif
  #ifdef INT1
  #define SPI_INT1_MASK  (1<<INT1)
  #endif
  #ifdef INT2
  #define SPI_INT2_MASK  (1<<INT2)
  #endif
#endif

void SPIClass2::usingInterrupt(uint8_t interruptNumber)
{
  uint8_t mask = 0;
  uint8_t sreg = SREG;
  noInterrupts(); // Protect from a scheduler and prevent transactionBegin
  switch (interruptNumber) {
  #ifdef SPI_INT0_MASK
  case 0: mask = SPI_INT0_MASK; break;
  #endif
  #ifdef SPI_INT1_MASK
  case 1: mask = SPI_INT1_MASK; break;
  #endif
  #ifdef SPI_INT2_MASK
  case 2: mask = SPI_INT2_MASK; break;
  #endif
  #ifdef SPI_INT3_MASK
  case 3: mask = SPI_INT3_MASK; break;
  #endif
  #ifdef SPI_INT4_MASK
  case 4: mask = SPI_INT4_MASK; break;
  #endif
  #ifdef SPI_INT5_MASK
  case 5: mask = SPI_INT5_MASK; break;
  #endif
  #ifdef SPI_INT6_MASK
  case 6: mask = SPI_INT6_MASK; break;
  #endif
  #ifdef SPI_INT7_MASK
  case 7: mask = SPI_INT7_MASK; break;
  #endif
  default:
    interruptMode = 2;
    break;
  }
  interruptMask |= mask;
  if (!interruptMode)
    interruptMode = 1;
  SREG = sreg;
}

void SPIClass2::notUsingInterrupt(uint8_t interruptNumber)
{
  // Once in mode 2 we can't go back to 0 without a proper reference count
  if (interruptMode == 2)
    return;
  uint8_t mask = 0;
  uint8_t sreg = SREG;
  noInterrupts(); // Protect from a scheduler and prevent transactionBegin
  switch (interruptNumber) {
  #ifdef SPI_INT0_MASK
  case 0: mask = SPI_INT0_MASK; break;
  #endif
  #ifdef SPI_INT1_MASK
  case 1: mask = SPI_INT1_MASK; break;
  #endif
  #ifdef SPI_INT2_MASK
  case 2: mask = SPI_INT2_MASK; break;
  #endif
  #ifdef SPI_INT3_MASK
  case 3: mask = SPI_INT3_MASK; break;
  #endif
  #ifdef SPI_INT4_MASK
  case 4: mask = SPI_INT4_MASK; break;
  #endif
  #ifdef SPI_INT5_MASK
  case 5: mask = SPI_INT5_MASK; break;
  #endif
  #ifdef SPI_INT6_MASK
  case 6: mask = SPI_INT6_MASK; break;
  #endif
  #ifdef SPI_INT7_MASK
  case 7: mask = SPI_INT7_MASK; break;
  #endif
  default:
    break;
    // this case can't be reached
  }
  interruptMask &= ~mask;
  if (!interruptMask)
    interruptMode = 0;
  SREG = sreg;
}
